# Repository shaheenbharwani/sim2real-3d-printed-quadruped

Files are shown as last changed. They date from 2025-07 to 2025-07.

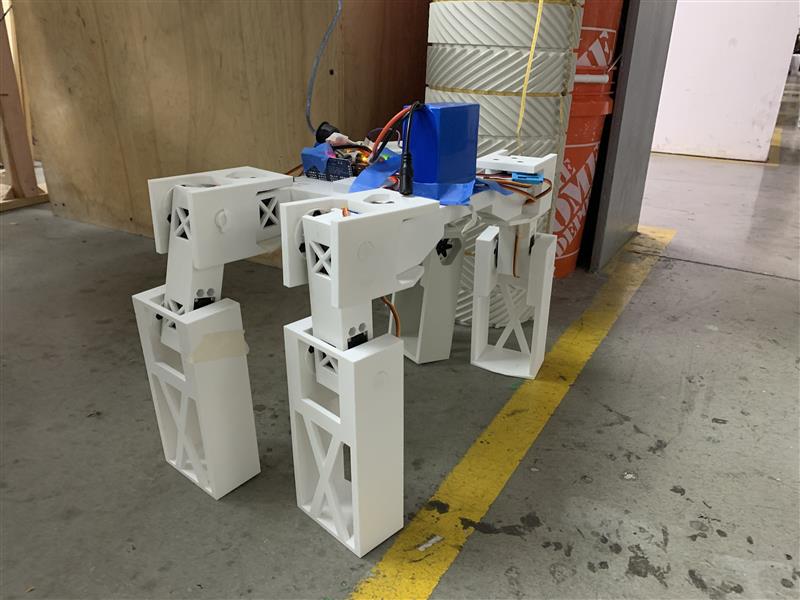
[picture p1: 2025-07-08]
media/quad_pic2.jpg

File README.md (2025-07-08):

# AI Quadruped Robot: Complete Sim-to-Real Pipeline

quad_pic1

**Complete open-source quadruped robot with AI-driven locomotion trained in Isaac Lab and deployed on physical hardware via ROS2.**

## Overview

This project demonstrates a full sim-to-real transfer pipeline: training a quadruped robot to walk in Isaac Lab simulation, then deploying the trained neural network to a physical 3D-printed robot via ROS2 and Arduino.

## Features

- **Full sim-to-real pipeline**: Isaac Lab → PyTorch → ROS2 → Physical robot
- **AI-powered locomotion**: Neural network trained with reinforcement learning
- **Real-time control**: 20Hz inference with responsive keyboard control
- **Modular design**: Easy to modify and extend
- **Complete documentation**: Hardware assembly to software deployment

## What You'll Build

A 12-DOF quadruped robot controlled by an AI trained in simulation that responds to velocity commands and walks autonomously.

## Performance Metrics

- **Training**: 999 episodes in Isaac Lab
- **Control Frequency**: 20Hz AI inference, 5Hz Arduino communication  
- **Servo Count**: 12x MG996R servos
- **Power**: External 6V supply
- **Communication**: USB serial (Windows → WSL → Arduino)
- **Observation Space**: 72 dimensions
- **Action Space**: 12 joint position targets

## Hardware Specifications

### Core Components
- **12x MG996R Servos** (3 per leg: hip, knee, ankle)
- **Arduino UNO R3** with PCA9685 I2C servo driver
- **External 6V power supply** for servos
- **3D printed chassis** (STL files included)

### Joint Configuration
- **DOF**: 12 total (3 per leg)
- **Joint Names**: `front_left_hip`, `front_left_knee`, `front_left_ankle`, etc.
- **Range**: 0-180 degrees with custom angle conversions
- **Control**: Position control via PWM

## Software Stack

### Training Environment
- **Isaac Lab**: NVIDIA's robotics simulation platform
- **Robot Model**: Custom URDF with 165 mesh components
- **Training Algorithm**: Reinforcement learning via RSL-RL
- **Export Format**: PyTorch JIT (.pt)

### Deployment Stack
- **ROS2 Jazzy**: Real-time robot control system
- **Ubuntu 22.04 WSL**: Development environment
- **PyTorch**: Neural network inference engine
- **Arduino**: Hardware interface and servo control

## Quick Start

### 1. Hardware Assembly
```bash
# See docs/hardware/assembly.md for detailed instructions
# Required: 3D printer, basic electronics tools
```

### 2. Software Setup
```bash
# Install ROS2 Jazzy
sudo apt update && sudo apt install ros-jazzy-desktop

# Create workspace
mkdir -p ~/ros2_ws/src
cd ~/ros2_ws/src

# Clone repository
git clone <this-repo>
cd ..

# Build packages
colcon build
source install/setup.bash
```

### 3. AI Training (Optional)
```bash
# Install Isaac Lab
# See docs/training/isaac_lab_setup.md

# Train model (or use provided pre-trained model)
python scripts/train_quadruped.py
```

### 4. Robot Deployment
```bash
# Terminal 1: Hardware interface
ros2 run arduino_control quadruped_controller

# Terminal 2: AI controller  
ros2 run arduino_control ai_controller

# Terminal 3: Keyboard control
ros2 run arduino_control velocity_controller
```

## Controls

- **W**: Forward motion
- **S**: Backward motion  
- **A**: Strafe left
- **D**: Strafe right
- **Q**: Turn left
- **E**: Turn right
- **X**: Gradual stop
- **SPACE**: Emergency stop

## Repository Structure

```
sim2real-3d-printed-quadruped/
├── README.md                   # This file
├── docs/                       # Documentation
│   ├── hardware/              # Assembly guides, BOM
│   ├── software/              # Installation, setup  
│   └── training/              # Isaac Lab guides
├── hardware/                   # CAD files, URDF, electronics
├── ros2_workspace/            # ROS2 packages
│   └── src/                   # AI controller, hardware interface
├── arduino/                    # Arduino firmware
├── simulation/                 # Isaac Lab files, trained models
└── media/                     # Videos, images, demos
```

## Technical Achievements

1. **Sim-to-Real Transfer**: Successfully deployed Isaac Lab trained model on physical hardware
2. **Real-time AI Inference**: PyTorch model running at 20Hz on physical robot  
3. **Robust Communication**: Reliable ROS2 → Arduino → Servo pipeline
4. **Modular Architecture**: Separate controllers for AI, hardware, and user input
5. **Production-Ready**: Stable, error-free operation for extended periods

## System Architecture

```
┌─────────────┐    ┌──────────────┐    ┌─────────────┐    ┌─────────────┐
│ Isaac Lab   │───▶│ PyTorch      │───▶│ ROS2        │───▶│ Arduino     │
│ Training    │    │ Model (.pt)  │    │ AI Node     │    │ + PCA9685   │
└─────────────┘    └──────────────┘    └─────────────┘    └─────────────┘
                                              │                    │
┌─────────────┐    ┌──────────────┐          │                    ▼
│ Keyboard    │───▶│ Velocity     │──────────┘            ┌─────────────┐
│ Input       │    │ Commands     │                       │ 12x Servos  │
└─────────────┘    └──────────────┘                       │ (Physical   │
                                                          │ Robot)      │
                                                          └─────────────┘
```

## AI Model Details

- **Observation Vector**: 72 dimensions
  - Base velocity (6D)
  - Gravity vector (3D)  
  - Velocity commands (3D)
  - Joint positions (12D)
  - Joint velocities (12D)
  - Previous actions (12D)
  - Foot forces (24D)

- **Action Vector**: 12 dimensions (joint position targets)
- **Network Architecture**: Policy network exported from Isaac Lab
- **Training Time**: 999 episodes (~20 minutes)

## Hardware Interface

### Arduino Firmware Features
- **Serial Communication**: Receives joint commands via USB
- **Servo Control**: PCA9685 I2C driver for 12 servos
- **Angle Conversion**: Handles negative angles for specific joints
- **Safety Limits**: Constrains servo range to prevent damage

### ROS2 Controllers
1. **AI Controller**: Loads PyTorch model, runs inference, publishes joint commands
2. **Velocity Controller**: Processes keyboard input, publishes velocity commands  
3. **Hardware Controller**: Interfaces with Arduino, converts ROS messages to serial

## Future Enhancements

- **Vision Integration**: Camera-based navigation
- **Advanced Gaits**: Implement trot, bound, gallop
- **Terrain Adaptation**: Rough terrain walking
- **Mobile Control**: Smartphone app interface
- **Sensor Fusion**: IMU, encoders, force sensors

## Contributing

Contributions welcome! Areas of focus:
- **Hardware**: CAD improvements, new components
- **Software**: Better algorithms, new features  
- **Documentation**: Tutorials, troubleshooting
- **Testing**: Hardware validation, performance optimization

See [CONTRIBUTING.md](CONTRIBUTING.md) for guidelines.

## License

MIT License - see [LICENSE](LICENSE)

## Acknowledgments

- **NVIDIA Isaac Lab** for simulation platform
- **ROS2 Community** for robotics middleware
- **Arduino Community** for hardware interface tools

## Support

- **Issues**: Use GitHub Issues for bug reports
- **Discussions**: GitHub Discussions for questions
- **Wiki**: Detailed technical documentation

---

**Built with ❤️ for the open-source robotics community**

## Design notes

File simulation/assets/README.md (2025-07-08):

# Isaac Lab Assets

## Robot Model Files

### USD File Location
The trained robot model is: `C:/Users/Shaheen Bharwani/Documents/SCI-Arc/Thesis/Original_Quad_URDF_Export/quad5.usd`

**Note**: This 7MB USD file contains the complete robot model with 165 mesh components. To use:
1. Copy `quad5.usd` to `simulation/assets/` 
2. Update path in `my_quadruped_config.py` if needed

### Training Results
- **Episodes**: 999 (approximately 2 hours)
- **Model Export**: `/mnt/d/IsaacLab/logs/rsl_rl/my_quadruped/2025-06-16_22-35-31/exported/policy.pt`
- **Observation Space**: 72 dimensions
- **Action Space**: 12 joint positions

### Joint Configuration
Robot uses `rear_*` joint naming (not `back_*`) to match URDF:
- 4 legs × 3 joints = 12 DOF total
- Hip, knee, ankle per leg
- Position control with stiffness=120.0, damping=20.0

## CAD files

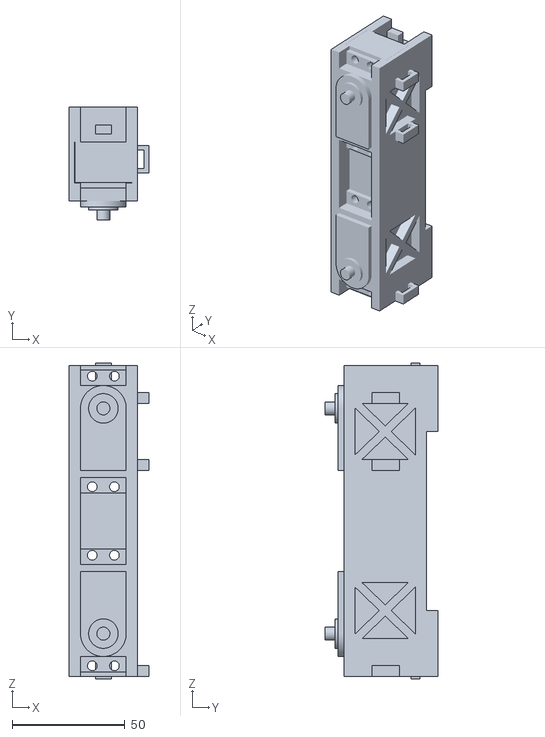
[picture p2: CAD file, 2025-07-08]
hardware/stl_files/rear_left_lower_leg.stl
35.3 x 50.1 x 140.3

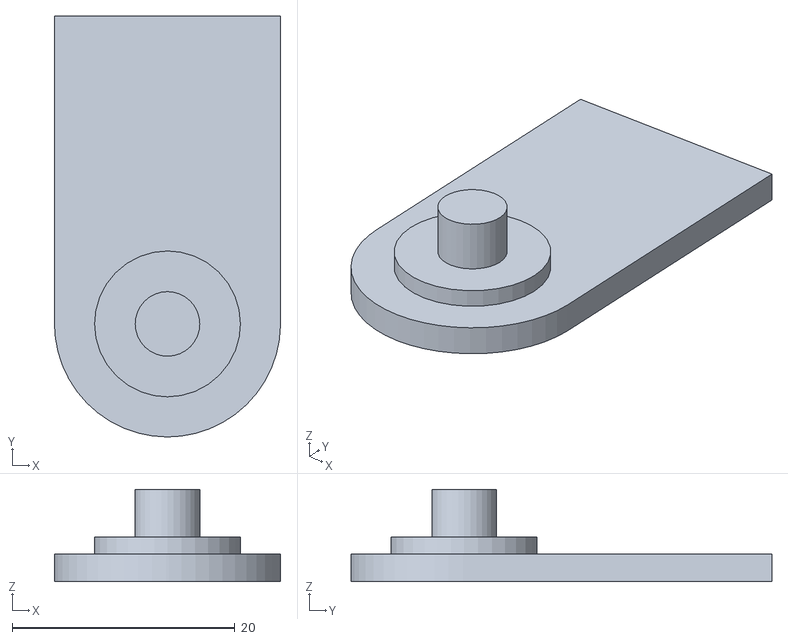
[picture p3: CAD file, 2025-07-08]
hardware/urdf/meshes/mesh154.obj
20.3 x 37.8 x 8.30

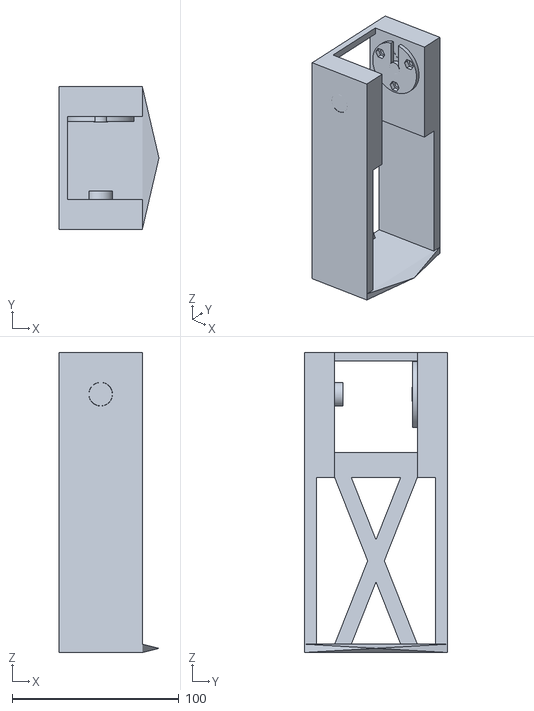
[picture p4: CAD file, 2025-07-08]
hardware/stl_files/front_left_foot.stl
60.0 x 85.6 x 180.0

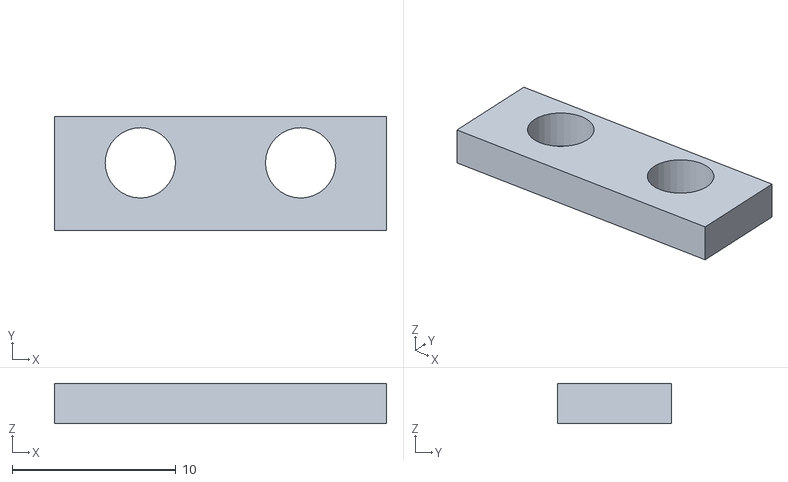
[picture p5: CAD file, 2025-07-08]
hardware/urdf/meshes/mesh109.obj
20.3 x 7.00 x 2.45

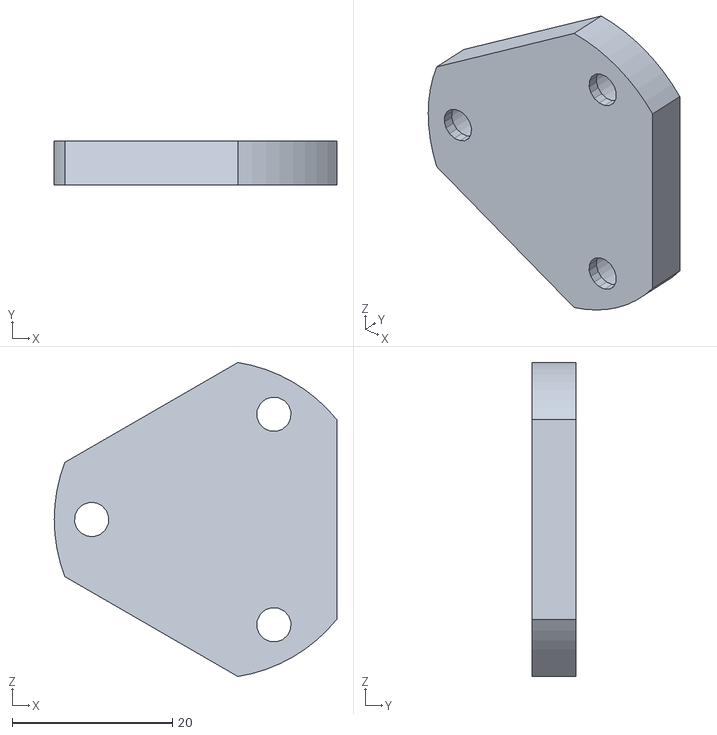
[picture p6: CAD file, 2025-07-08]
hardware/urdf/meshes/mesh98.obj
35.3 x 5.48 x 39.2

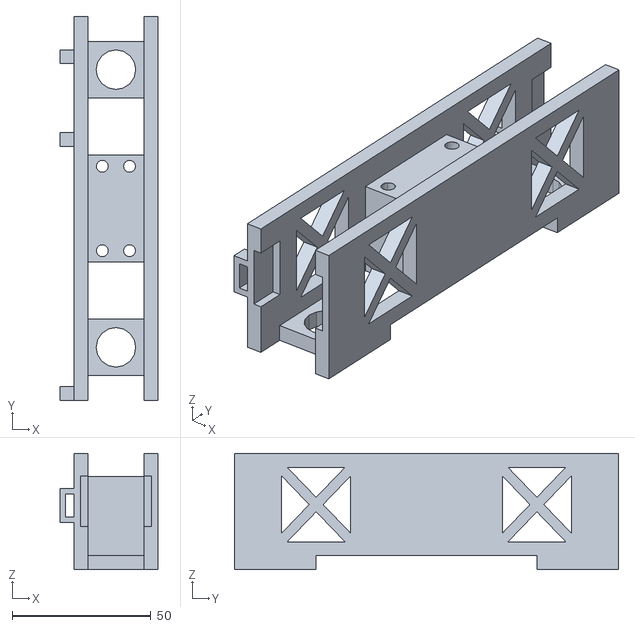
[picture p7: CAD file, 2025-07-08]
hardware/urdf/meshes/mesh124.obj
35.3 x 138.3 x 41.8

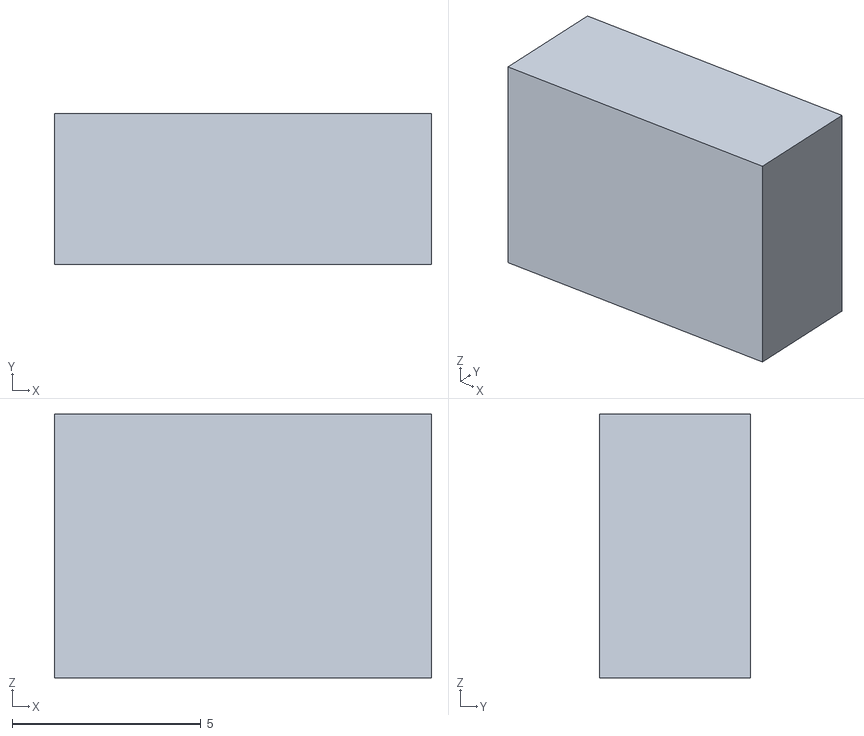
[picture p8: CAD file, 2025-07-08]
hardware/urdf/meshes/mesh70.obj
10.0 x 4.00 x 7.00

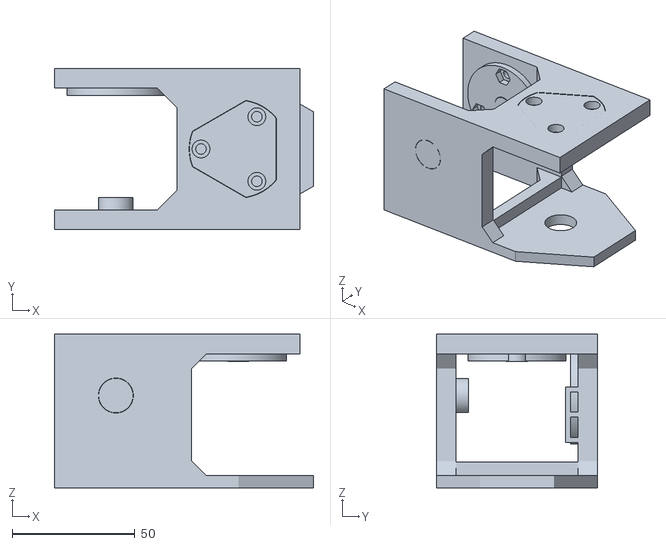
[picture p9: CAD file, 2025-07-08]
hardware/stl_files/front_left_upper_leg.stl
105.5 x 65.6 x 62.6

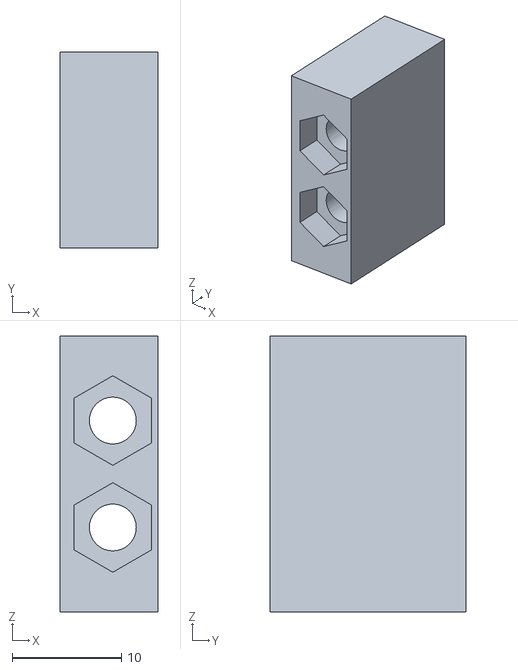
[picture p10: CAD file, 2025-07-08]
hardware/urdf/meshes/mesh54.obj
9.00 x 18.0 x 25.3

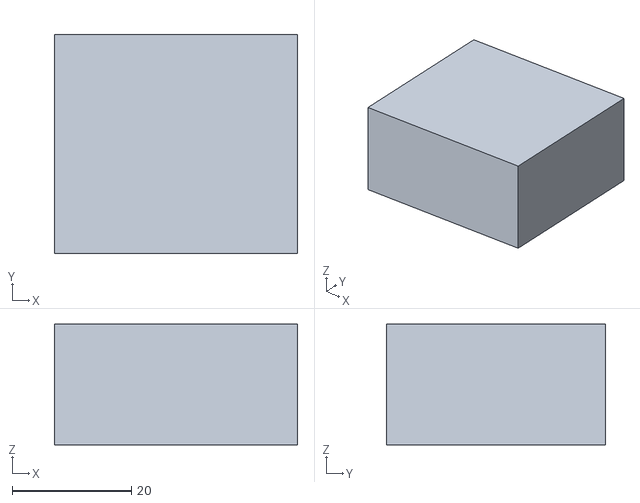
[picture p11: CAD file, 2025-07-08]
hardware/urdf/meshes/mesh12.obj
40.8 x 36.8 x 20.3

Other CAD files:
hardware/stl_files/rear_left_foot.stl
hardware/stl_files/rear_right_foot.stl
hardware/stl_files/front_left_lower_leg.stl
hardware/urdf/meshes/mesh6.obj
hardware/stl_files/front_right_foot.stl
hardware/stl_files/front_right_lower_leg.stl
hardware/urdf/meshes/mesh107.obj
hardware/stl_files/front_right_upper_leg.stl
hardware/stl_files/rear_left_upper_leg.stl
hardware/stl_files/rear_right_lower_leg.stl
hardware/stl_files/rear_right_upper_leg.stl
hardware/urdf/meshes/mesh0.obj
hardware/urdf/meshes/mesh1.obj
hardware/urdf/meshes/mesh10.obj
hardware/urdf/meshes/mesh100.obj
hardware/urdf/meshes/mesh101.obj
hardware/urdf/meshes/mesh102.obj
hardware/urdf/meshes/mesh103.obj
hardware/urdf/meshes/mesh104.obj
hardware/urdf/meshes/mesh105.obj
hardware/urdf/meshes/mesh106.obj
hardware/urdf/meshes/mesh108.obj
hardware/urdf/meshes/mesh110.obj
hardware/urdf/meshes/mesh111.obj
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

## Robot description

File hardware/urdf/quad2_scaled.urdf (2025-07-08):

<?xml version='1.0' encoding='utf-8'?>
<robot name="quad2">
  <joint name="front_left_ankle" type="revolute">
    <origin xyz="0.000000 -10.000000 0.000000" rpy="0. 0. 0." />
    <parent link="front_left_lower_leg" />
    <child link="front_left_foot" />
    <axis xyz="0. 0. 1." />
    <limit lower="0." upper="3.1415927" effort="0." velocity="0." />
  </joint>
  <joint name="front_left_hip" type="revolute">
    <origin xyz="-31.015000 24.810300 -19.280000" rpy="0. 0. 0." />
    <parent link="Root" />
    <child link="front_left_upper_leg" />
    <axis xyz="0. 1. 0." />
    <limit lower="-1.5707963" upper="1.5707963" effort="0." velocity="0." />
  </joint>
  <joint name="front_left_knee" type="revolute">
    <origin xyz="-4.985001 0.689700 -0.090300" rpy="0. 0. 0." />
    <parent link="front_left_upper_leg" />
    <child link="front_left_lower_leg" />
    <axis xyz="0. 0. 1." />
    <limit lower="-3.1415927" upper="0." effort="0." velocity="0." />
  </joint>
  <joint name="front_right_ankle" type="revolute">
    <origin xyz="0.000000 -10.000000 0.000000" rpy="0. 0. 0." />
    <parent link="front_right_lower_leg" />
    <child link="front_right_foot" />
    <axis xyz="0. 0. 1." />
    <limit lower="-3.1415927" upper="0." effort="0." velocity="0." />
  </joint>
  <joint name="front_right_hip" type="revolute">
    <origin xyz="-7.485000 24.810300 -19.280000" rpy="0. 0. 0." />
    <parent link="Root" />
    <child link="front_right_upper_leg" />
    <axis xyz="0. 1. 0." />
    <limit lower="-1.5707963" upper="1.5707963" effort="0." velocity="0." />
  </joint>
  <joint name="front_right_knee" type="revolute">
    <origin xyz="4.985000 0.689700 -0.090300" rpy="0. 0. 0." />
    <parent link="front_right_upper_leg" />
    <child link="front_right_lower_leg" />
    <axis xyz="0. 0. 1." />
    <limit lower="0." upper="3.1415927" effort="0." velocity="0." />
  </joint>
  <joint name="rear_left_ankle" type="revolute">
    <origin xyz="0.000000 -10.000000 0.000000" rpy="0. 0. 0." />
    <parent link="rear_left_lower_leg" />
    <child link="rear_left_foot" />
    <axis xyz="0. 0. 1." />
    <limit lower="0." upper="3.1415927" effort="0." velocity="0." />
  </joint>
  <joint name="rear_left_hip" type="revolute">
    <origin xyz="-31.015000 24.810300 -4.280000" rpy="0. 0. 0." />
    <parent link="Root" />
    <child link="rear_left_upper_leg" />
    <axis xyz="0. 1. 0." />
    <limit lower="-1.5707963" upper="1.5707963" effort="0." velocity="0." />
  </joint>
  <joint name="rear_left_knee" type="revolute">
    <origin xyz="-4.985001 0.689700 0.090300" rpy="0. 0. 0." />
    <parent link="rear_left_upper_leg" />
    <child link="rear_left_lower_leg" />
    <axis xyz="0. 0. 1." />
    <limit lower="-3.1415927" upper="0." effort="0." velocity="0." />
  </joint>
  <joint name="rear_right_ankle" type="revolute">
    <origin xyz="0.000000 -10.000000 0.000000" rpy="0. 0. 0." />
    <parent link="rear_right_lower_leg" />
    <child link="rear_right_foot" />
    <axis xyz="0. 0. 1." />
    <limit lower="-3.1415927" upper="0." effort="0." velocity="0." />
  </joint>
  <joint name="rear_right_hip" type="revolute">
    <origin xyz="-7.485000 24.810300 -4.280000" rpy="0. 0. 0." />
    <parent link="Root" />
    <child link="rear_right_upper_leg" />
    <axis xyz="0. 1. 0." />
    <limit lower="-1.5707963" upper="1.5707963" effort="0." velocity="0." />
  </joint>
  <joint name="rear_right_knee" type="revolute">
    <origin xyz="4.985000 0.689700 0.090300" rpy="0. 0. 0." />
    <parent link="rear_right_upper_leg" />
    <child link="rear_right_lower_leg" />
    <axis xyz="0. 0. 1." />
    <limit lower="0." upper="3.1415927" effort="0." velocity="0." />
  </joint>
  <link name="Root">
    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
  </link>
  <link name="front_left_foot">
    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
  </link>
  <link name="front_left_lower_leg">
    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
  </link>
  <link name="front_left_upper_leg">
    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
  </link>
  <link name="front_right_foot">
    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
  </link>
  <link name="front_right_lower_leg">
    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
  </link>
  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
</robot>

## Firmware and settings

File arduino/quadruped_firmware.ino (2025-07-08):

#include <Wire.h>
#include <Adafruit_PWMServoDriver.h>

Adafruit_PWMServoDriver pwm = Adafruit_PWMServoDriver(0x40);

#define FREQUENCY_OSCILLATOR 25000000
#define SERVO_FREQ 50
#define SERVO_MIN 102
#define SERVO_MAX 500

// Servos that should convert negative angles to positive angles
// Add the channels that aren't working properly here
int negativeAngleServos[] = {1, 5, 8, 10}; // front_left_knee, front_right_ankle, rear_right_ankle, rear_left_knee
int numNegativeAngleServos = 4;

void setup() {
  Serial.begin(9600);
  Serial.println("R3 with Basic Servo Control - Negative Angle Handler");
  
  Wire.begin();
  pwm.begin();
  pwm.setOscillatorFrequency(FREQUENCY_OSCILLATOR);
  pwm.setPWMFreq(SERVO_FREQ);
  delay(10);
  
  Serial.println("Ready for servo commands");
  Serial.println("Commands: servo <channel> <angle>");
  Serial.println("Example: servo 0 90");
  
  // Print which servos handle negative angles
  Serial.print("Servos with negative angle conversion: ");
  for(int i = 0; i < numNegativeAngleServos; i++) {
    Serial.print(negativeAngleServos[i]);
    if(i < numNegativeAngleServos - 1) Serial.print(", ");
  }
  Serial.println();
}

void loop() {
  if (Serial.available() > 0) {
    String input = Serial.readStringUntil('\n');
    input.trim();
    
    if (input.startsWith("servo ")) {
      // Parse: "servo 0 90" or "servo 1 -35"
      int space1 = input.indexOf(' ');
      int space2 = input.indexOf(' ', space1 + 1);
      
      if (space1 > 0 && space2 > 0) {
        int channel = input.substring(space1 + 1, space2).toInt();
        int angle = input.substring(space2 + 1).toInt();
        
        setServoAngle(channel, angle);
        Serial.print("Moved servo ");
        Serial.print(channel);
        Serial.print(" to ");
        Serial.println(angle);
      }
    } else {
      Serial.print("Echo: ");
      Serial.println(input);
    }
  }
}

bool isNegativeAngleServo(int channel) {
  for(int i = 0; i < numNegativeAngleServos; i++) {
    if(negativeAngleServos[i] == channel) {
      return true;
    }
  }
  return false;
}

void setServoAngle(int channel, int angle) {
  int originalAngle = angle;
  
  // Handle negative angles for specific servos
  if (isNegativeAngleServo(channel) && angle < 0) {
    angle = abs(angle); // Convert negative to positive
    Serial.print("Channel ");
    Serial.print(channel);
    Serial.print(" converted ");
    Serial.print(originalAngle);
    Serial.print("° to ");
    Serial.print(angle);
    Serial.println("°");
  }
  
  // Constrain to servo range
  angle = constrain(angle, 0, 180);
  
  // Convert angle to PWM pulse length
  uint16_t pulseLength = map(angle, 0, 180, SERVO_MIN, SERVO_MAX);
  pwm.setPWM(channel, 0, pulseLength);
}

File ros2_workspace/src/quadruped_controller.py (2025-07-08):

#!/usr/bin/env python3

import rclpy
from rclpy.node import Node
from std_msgs.msg import Float64
from sensor_msgs.msg import JointState
import serial
import time
import math

class QuadrupedController(Node):
    def __init__(self):
        super().__init__('quadruped_controller')
        
        # Parameters
        self.declare_parameter('serial_port', '/dev/ttyACM0')
        self.declare_parameter('baud_rate', 9600)
        
        # Get parameters
        self.serial_port = self.get_parameter('serial_port').value
        self.baud_rate = self.get_parameter('baud_rate').value
        
        # Joint name to servo channel mapping
        self.joint_to_channel = {
            'front_left_hip': 0,
            'front_left_knee': 1, 
            'front_left_ankle': 2,
            'front_right_hip': 3,
            'front_right_knee': 4,
            'front_right_ankle': 5,
            'rear_left_hip': 9,
            'rear_left_knee': 10,
            'rear_left_ankle': 11,
            'rear_right_hip': 6,
            'rear_right_knee': 7,
            'rear_right_ankle': 8
        }
        
        # Reverse mapping for feedback
        self.channel_to_joint = {v: k for k, v in self.joint_to_channel.items()}
        
        # Current joint positions (in degrees)
        self.current_positions = {}
        for joint in self.joint_to_channel.keys():
            if 'hip' in joint:
                self.current_positions[joint] = 0.0  # Hip joints at 90°
            else:  # knee and ankle joints
                self.current_positions[joint] = 0.0  # Knee/ankle joints at 0 degrees
        
        # Initialize serial connection
        self.serial_connection = None
        self.connect_to_arduino()
        
        # ROS2 Subscribers
        self.joint_state_sub = self.create_subscription(
            JointState,
            '/joint_states',
            self.joint_state_callback,
            10
        )
        
        # Individual joint command subscriber for testing
        self.joint_cmd_sub = self.create_subscription(
            Float64,
            '/quadruped_joint_cmd',
            self.test_joint_callback,
            10
        )
        
        # Publisher for joint feedback
        self.joint_feedback_pub = self.create_publisher(
            JointState,
            '/quadruped_feedback',
            10
        )
        
        # Timer for status updates
        self.status_timer = self.create_timer(2.0, self.publish_feedback)
        
        self.get_logger().info(f'Quadruped Controller started on {self.serial_port}')
        self.get_logger().info(f'Joint mapping: {list(self.joint_to_channel.keys())}')
        self.get_logger().info(f'Listening for joint states on /joint_states')
        self.get_logger().info(f'Test commands on /quadruped_joint_cmd')
        
    def connect_to_arduino(self):
        """Connect to Arduino via serial"""
        try:
            self.serial_connection = serial.Serial(
                self.serial_port, 
                self.baud_rate, 
                timeout=1
            )
            time.sleep(3)  # Wait for Arduino to initialize
            
            # Read any startup messages
            while self.serial_connection.in_waiting > 0:
                msg = self.serial_connection.readline().decode('utf-8').strip()
                if msg:
                    self.get_logger().info(f'Arduino: {msg}')
                
            self.get_logger().info('Successfully connected to Arduino')
            
            # Test connection
            if self.send_arduino_command('echo test'):
                self.get_logger().info('Arduino communication verified')

            # Move to default positions to match URDF
            self.get_logger().info('Setting default joint positions...')
            for joint_name, default_angle in self.current_positions.items():
                self.move_joint(joint_name, default_angle)
                time.sleep(0.1)  # Brief delay between servo commands
            self.get_logger().info('Default positions set')
            
        except Exception as e:
            self.get_logger().error(f'Failed to connect to Arduino: {e}')
            self.serial_connection = None
    
    def send_arduino_command(self, command):
        """Send command to Arduino and read response"""
        if self.serial_connection is None:
            self.get_logger().error('No Arduino connection')
            return False

        try:
            # Send command
            self.serial_connection.write(f'{command}\n'.encode('utf-8'))
            self.get_logger().info(f'ACTUAL COMMAND SENT: {command}')  # ADD THIS LINE
        
            # Give Arduino time to process and respond
            time.sleep(0.2)
        
            # Read ALL available responses
            while self.serial_connection.in_waiting > 0:
                response = self.serial_connection.readline().decode('utf-8').strip()
                if response:
                    self.get_logger().info(f'Arduino: {response}')  # Changed to INFO level

            return True
        except Exception as e:
            self.get_logger().error(f'Serial communication error: {e}')
            return False
    
    def test_joint_callback(self, msg):
        """Handle test joint command (for testing) - expects angle in degrees"""
        angle_degrees = msg.data
        
        # Test command - move front_left_hip
        test_joint = 'front_left_hip'
        self.move_joint(test_joint, angle_degrees)
    
    def joint_state_callback(self, msg):
        """Handle joint state messages from joint_state_publisher or other sources"""
        
        for i, joint_name in enumerate(msg.name):
            if joint_name in self.joint_to_channel and i < len(msg.position):
                # Convert radians to degrees
                angle_radians = msg.position[i]
                angle_degrees = math.degrees(angle_radians)
                
                # Joint-specific angle mapping to match robot's natural pose
                if 'hip' in joint_name:
                    # Hip joints: URDF 0° = standing position (servo 90°)
                    servo_angle = angle_degrees + 90
                else:
                    # Knee/ankle joints: URDF 0° = straight legs (servo 0°)
                    servo_angle = angle_degrees
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

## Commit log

2025-07-08 Add complete ROS2 workspace, Arduino firmware, and URDF model
    [quadruped.urdf]
2025-07-08 Updated URDF model and added USD file
    [mesh0.obj, mesh1.obj, mesh10.obj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]
2025-07-08 Add CAD models and media
2025-07-08 Add media and trained model
    [front_left_foot.stl, front_left_lower_leg.stl, front_left_upper_leg.stl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]
